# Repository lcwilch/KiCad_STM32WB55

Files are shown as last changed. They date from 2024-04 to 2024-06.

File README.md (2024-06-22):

# KiCad_STM32WB55
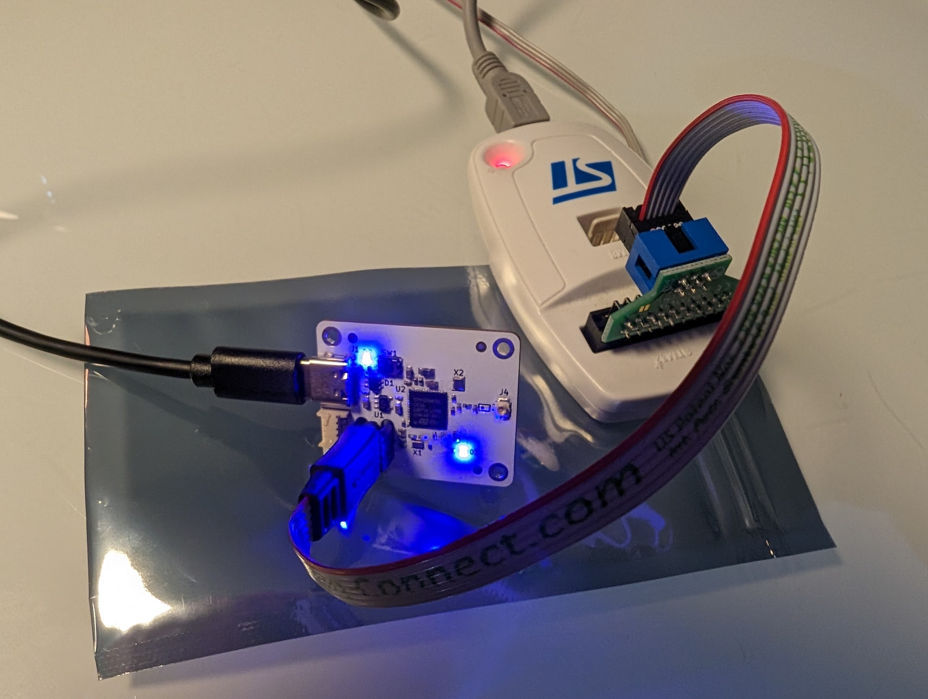
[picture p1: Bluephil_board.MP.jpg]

Finished https://www.youtube.com/watch?v=nkHFoxe0mrU&amp;t=3668s and successfully manufactured and brought-up board pictured above

# Bluephil
Contains KiCad project and manufacturing files and information
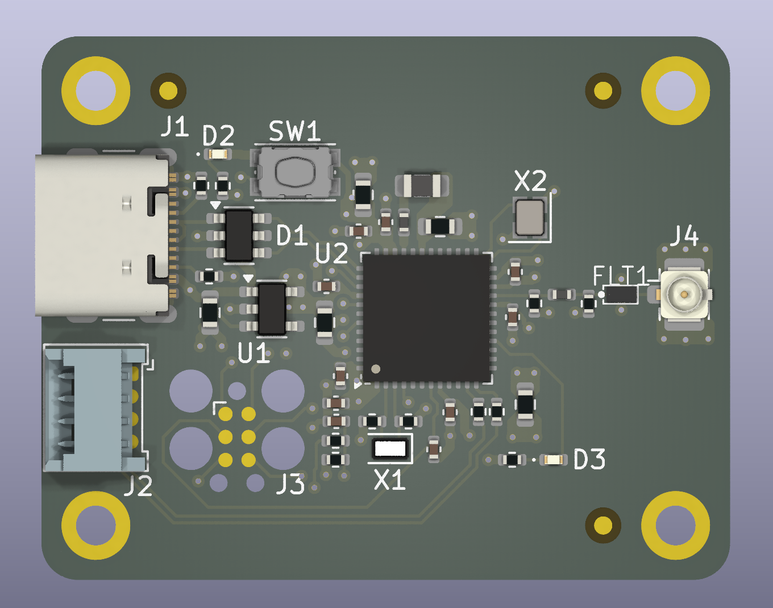
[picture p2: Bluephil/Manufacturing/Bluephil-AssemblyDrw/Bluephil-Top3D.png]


# STM32CubeIDE
Contains a STM32CubeIDE project that tests board SWD interface (for flashing and debug), debug LED GPIO, and USB FS CDC functionality

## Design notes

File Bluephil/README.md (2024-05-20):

# KiCad
Most files in this dir are related to the KiCad project

# Manufacturing
Contains files needed to manufacture board: Gerbers, BOM, component placement
Also contains assembly drawings and engineering/technical questions and answers when manufacturing via PCBWay

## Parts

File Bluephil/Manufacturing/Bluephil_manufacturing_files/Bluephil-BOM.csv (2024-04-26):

Reference | Value | Footprint | Qty | DNP | Description | Manufacturer | Manufacturer PN | Distributor Link
C1,C2,C3,C8,C16 | 4u7 | Resistor_SMD:R_0603_1608Metric | 5 |  | Unpolarized capacitor | Murata Electronics | GRM188Z71A475KE15J | https://www.mouser.com/ProductDetail/Murata-Electronics/GRM188Z71A475KE15J?qs=Ey7%2FXF42M3fe52ZB0l7gLw%3D%3D
C4,C5,C6,C7,C9,C10,C11,C12,C15,C19 | 100n | Capacitor_SMD:C_0402_1005Metric | 10 |  | Unpolarized capacitor | Murata Electronics | GRM155R71A104KA01J | https://www.mouser.com/ProductDetail/Murata-Electronics/GRM155R71A104KA01J?qs=9U7yHM2lsjQpBoriOS9Iag%3D%3D
C13,C14 | 10p | Resistor_SMD:R_0402_1005Metric | 2 |  | Unpolarized capacitor | KYOCERA AVX | 04026D100JAT2A | https://www.mouser.com/ProductDetail/KYOCERA-AVX/04026D100JAT2A?qs=gEbkM7q0lx%252BmQLS7sqmBjQ%3D%3D
C17 | 0p8 | Resistor_SMD:R_0402_1005Metric | 1 |  | Unpolarized capacitor | Murata Electronics | GRM1555C1HR80BA01D | https://www.mouser.com/ProductDetail/Murata-Electronics/GRM1555C1HR80BA01D?qs=e%252BE4OD6MgMezPYPintwvrA%3D%3D
C18 | 0p3 | Resistor_SMD:R_0402_1005Metric | 1 |  | Unpolarized capacitor | Murata Electronics | GRM1555C1HR30WA01D | https://www.mouser.com/ProductDetail/Murata-Electronics/GRM1555C1HR30WA01D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
D1 | USBLC6-2SC6 | Package_TO_SOT_SMD:SOT-23-6 | 1 |  | Very low capacitance ESD protection diode, 2 data-line, SOT-23-6 | STMicroelectronics | USBLC6-2SC6 | https://www.mouser.com/ProductDetail/STMicroelectronics/USBLC6-2SC6?qs=po45yt2pPpu%2FhNIlwQdTlg%3D%3D
D2,D3 | LED | LED_SMD:LED_0402_1005Metric | 2 |  | Light emitting diode | Kingbright | APHHS1005LQBC/D-V | https://www.mouser.com/ProductDetail/Kingbright/APHHS1005LQBC-D-V?qs=WbpYJYa8y32aFVn6IIj1Dg%3D%3D
FLT1 | DLF162500LT-5028A1 | Bluephil_PCBFootprints:DLF162500LT-5028A1 | 1 |  | Signal Conditioning LTCC LOW PASS FLTR 2400-2500MHz | TDK | DLF162500LT-5028A1 | https://www.mouser.com/ProductDetail/TDK/DLF162500LT-5028A1?qs=U%2FZX79kHR%2FlwIbAISCs3qA%3D%3D
J1 | USB_C_Receptacle_USB2.0_16P | Connector_USB:USB_C_Receptacle_GCT_USB4105-xx-A_16P_TopMnt_Horizontal | 1 |  | USB 2.0-only 16P Type-C Receptacle connector | GCT | USB4105-GF-A | https://www.mouser.com/ProductDetail/GCT/USB4105-GF-A?qs=KUoIvG%2F9IlY%2FMLlBMpStpA%3D%3D
J3 | Conn_01x04 | Connector_Molex:Molex_PicoBlade_53048-0410_1x04_P1.25mm_Horizontal | 1 |  | Generic connector, single row, 01x04, script generated (kicad-library-utils/schlib/autogen/connector/) | Molex | 53048-0410 | https://www.mouser.com/ProductDetail/Molex/53048-0410?qs=359VwiUTsp2msj5Tobchuw%3D%3D
J4 | Conn_Coaxial | Connector_Coaxial:U.FL_Hirose_U.FL-R-SMT-1_Vertical | 1 |  | coaxial connector (BNC, SMA, SMB, SMC, Cinch/RCA, LEMO, ...) | Hirose Connector | U.FL-R-SMT-1(10) | https://www.mouser.com/ProductDetail/Hirose-Connector/U.FL-R-SMT-110?qs=kL1ClTr6oBoOdtqlGQpQrQ%3D%3D
L1 | 10n | Inductor_SMD:L_0402_1005Metric | 1 |  | Inductor | Murata Electronics | LQG15WZ10NJ02D | https://www.mouser.com/ProductDetail/Murata-Electronics/LQG15WZ10NJ02D?qs=60uY6ySkanT1eJ7IaeAl%2Fg%3D%3D
L2 | 10u | Inductor_SMD:L_0805_2012Metric | 1 |  | Inductor | Murata Electronics | LQM21FN100M70L | https://www.mouser.com/ProductDetail/Murata-Electronics/LQM21FN100M70L?qs=8M15sSGRUn%252BogwBrvQUwLA%3D%3D
L3 | 2n7 | Inductor_SMD:L_0402_1005Metric | 1 |  | Inductor | Murata Electronics | LQG15HS2N7S02D | https://www.mouser.com/ProductDetail/Murata-Electronics/LQG15HS2N7S02D?qs=ctz47l0uL1AKrLI74yO5Qw%3D%3D
R1,R2,R7 | 5k1 | Resistor_SMD:R_0402_1005Metric | 3 |  | Resistor | KOA Speer | SG73P1EWTTP512J | https://www.mouser.com/ProductDetail/KOA-Speer/SG73P1EWTTP512J?qs=Jslch3jnSjlSuuKTSTqkRg%3D%3D
R3,R4,R5,R6,R8 | 220R | Resistor_SMD:R_0402_1005Metric | 5 |  | Resistor | KOA Speer | RK73H1ETTP2200F | https://www.mouser.com/ProductDetail/KOA-Speer/RK73H1ETTP2200F?qs=RHoMK1iCi09D%2FnGG1bjdHg%3D%3D
SW1 | SW_Push | Button_Switch_SMD:SW_Push_1P1T_NO_CK_KMR2 | 1 |  | Push button switch, generic, two pins | C&K | KMR231NGLFS | https://www.mouser.com/ProductDetail/CK/KMR231NGLFS?qs=sb%252But3Lm4x1Y5NsXXdZx2g%3D%3D
U1 | MIC5365-3.3YD5 | Package_TO_SOT_SMD:SOT-23-5 | 1 |  | 150mA Low-dropout Voltage Regulator, Vout 3.3V, Vin up to 5.5V, SOT-23-5 | Microchip Technology | MIC5365-3.3YD5-TR | https://www.mouser.com/ProductDetail/Microchip-Technology/MIC5365-3.3YD5-TR?qs=U6T8BxXiZAXzRinbbfZRrg%3D%3D
U2 | STM32WB55CEU6 | Package_DFN_QFN:QFN-48-1EP_7x7mm_P0.5mm_EP5.6x5.6mm | 1 |  | STMicroelectronics Arm Cortex-M4 MCU, 512KB flash, 256KB RAM, 64 MHz, 1.71-3.6V, 30 GPIO, UFQFPN48 | STMicroelectronics | STM32WB55CEU6 | https://www.mouser.com/ProductDetail/STMicroelectronics/STM32WB55CEU6?qs=l7cgNqFNU1h38DnIgipayw%3D%3D
X1 | 32k768 | Crystal:Crystal_SMD_2012-2Pin_2.0x1.2mm | 1 |  | Two pin crystal | NDK | NX2012SA-32.768K-STD-MUB-1 | https://www.mouser.com/ProductDetail/NDK/NX2012SA-32.768K-STD-MUB-1?qs=55YtniHzbhA%252B6%2Fl1MwFZaQ%3D%3D
X2 | 32M | Crystal:Crystal_SMD_2016-4Pin_2.0x1.6mm | 1 |  | Four pin crystal, GND on pins 2 and 4 | NDK | NX2016SA-32M-EXS00A-CS06465 | https://www.mouser.com/ProductDetail/NDK/NX2016SA-32M-EXS00A-CS06465?qs=w%2Fv1CP2dgqr82b0JjRnv4A%3D%3D

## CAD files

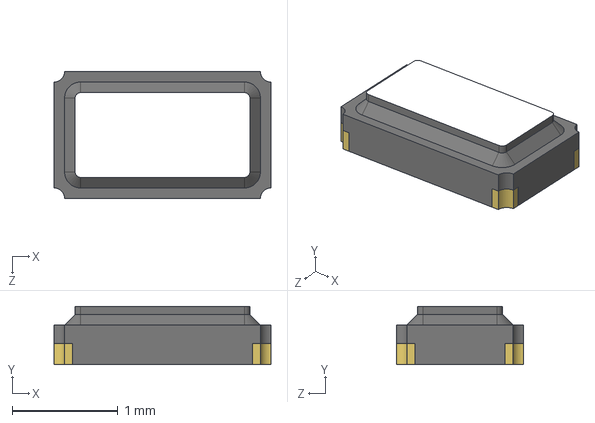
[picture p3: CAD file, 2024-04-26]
Bluephil/3DModels/NX2012SA-32.768K-STD-MUB-1.stp
2.05 x 0.55 x 1.20 mm

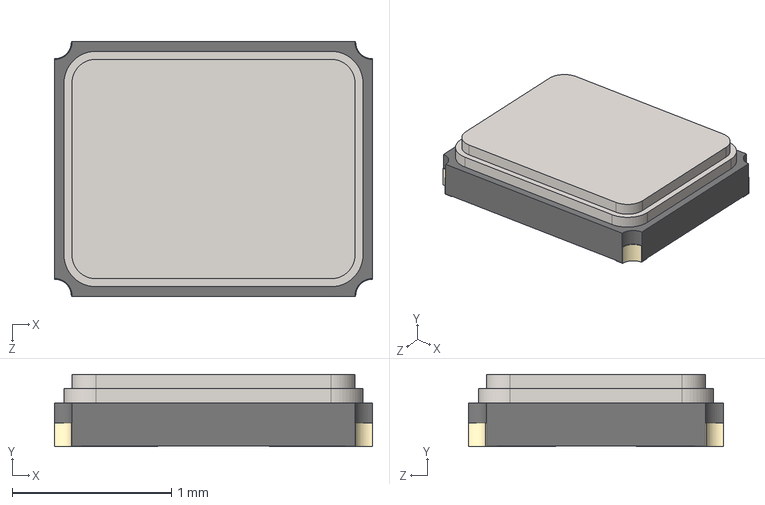
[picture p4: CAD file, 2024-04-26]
Bluephil/3DModels/NX2016SA-32M-EXS00A-CS06465.stp
2.00 x 0.455 x 1.60 mm

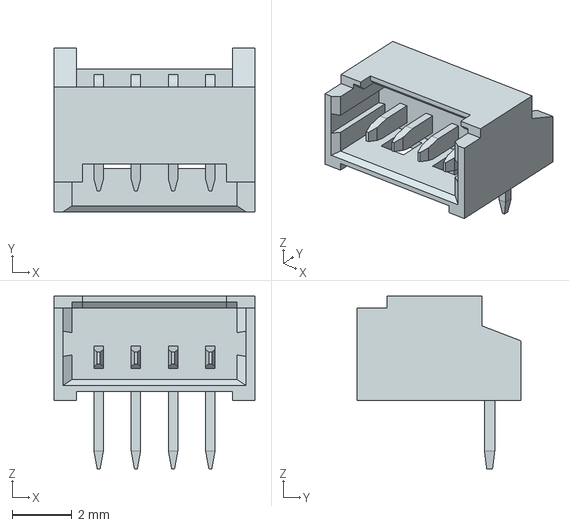
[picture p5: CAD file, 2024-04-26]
Bluephil/3DModels/Molex_PicoBlade_53048-0410_1x04_P1.25mm_Horizontal.stp
6.75 x 5.50 x 5.80 mm

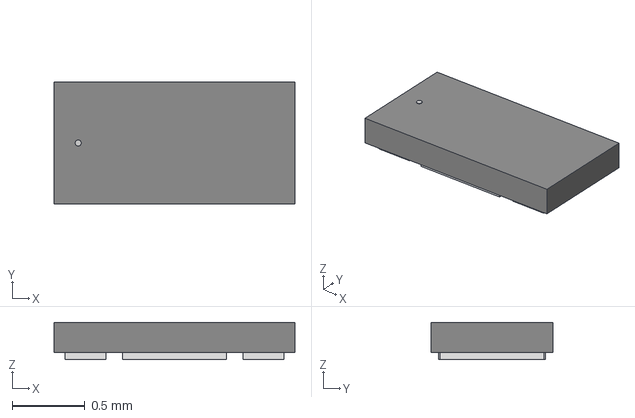
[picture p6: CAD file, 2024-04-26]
Bluephil/3DModels/DLF-4_1P6X0P8.step
1.65 x 0.838 x 0.257 mm

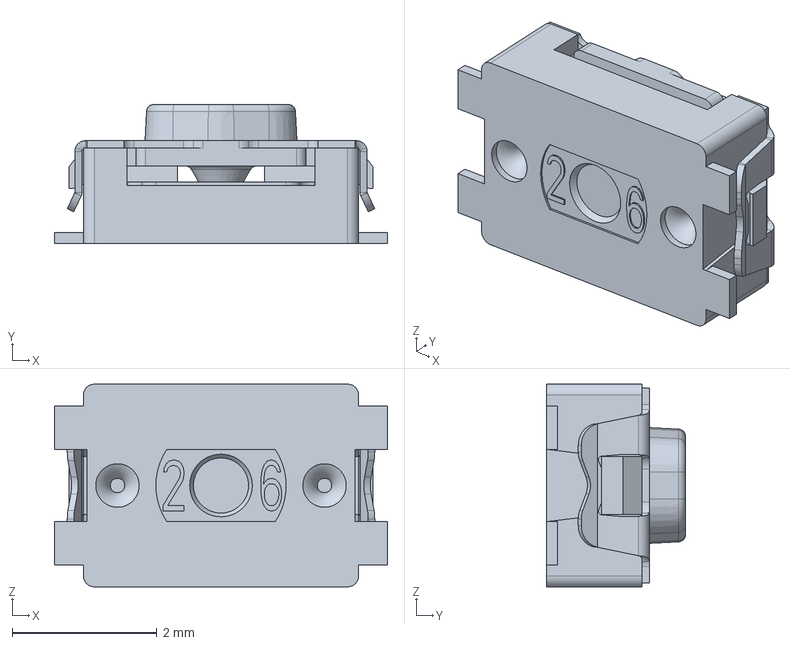
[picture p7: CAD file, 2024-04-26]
Bluephil/3DModels/KMR231NGLFS.stp
4.60 x 1.92 x 2.80 mm

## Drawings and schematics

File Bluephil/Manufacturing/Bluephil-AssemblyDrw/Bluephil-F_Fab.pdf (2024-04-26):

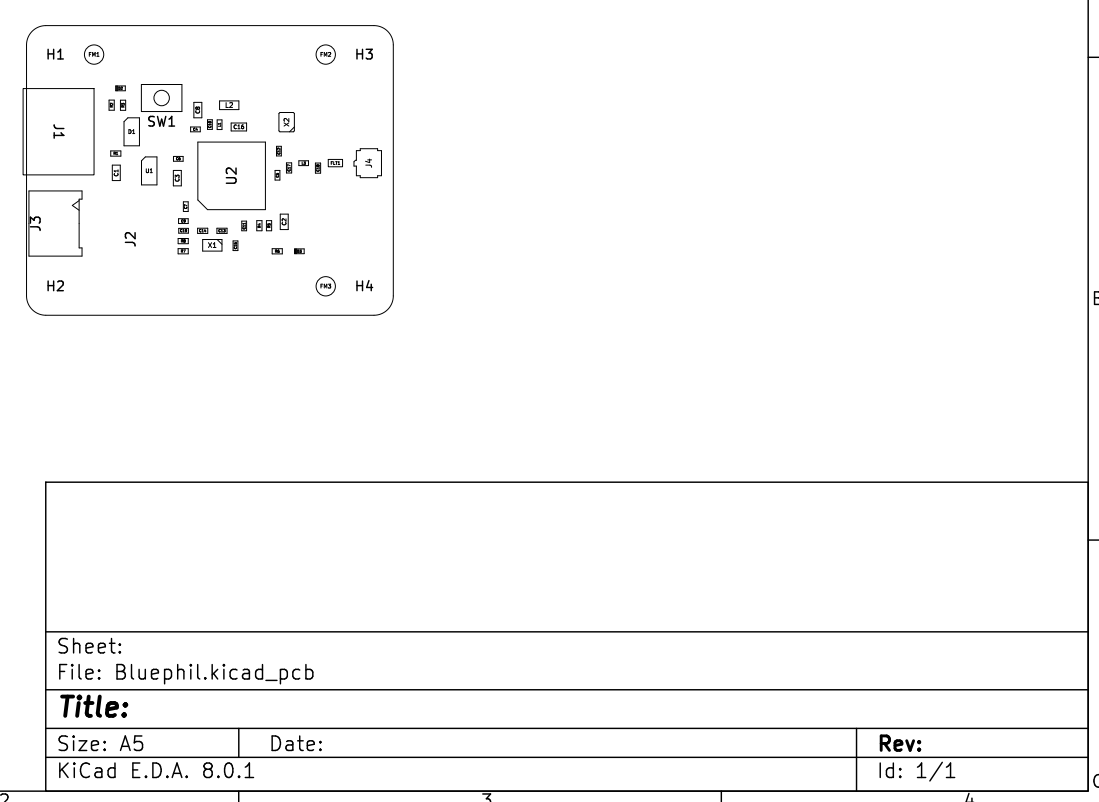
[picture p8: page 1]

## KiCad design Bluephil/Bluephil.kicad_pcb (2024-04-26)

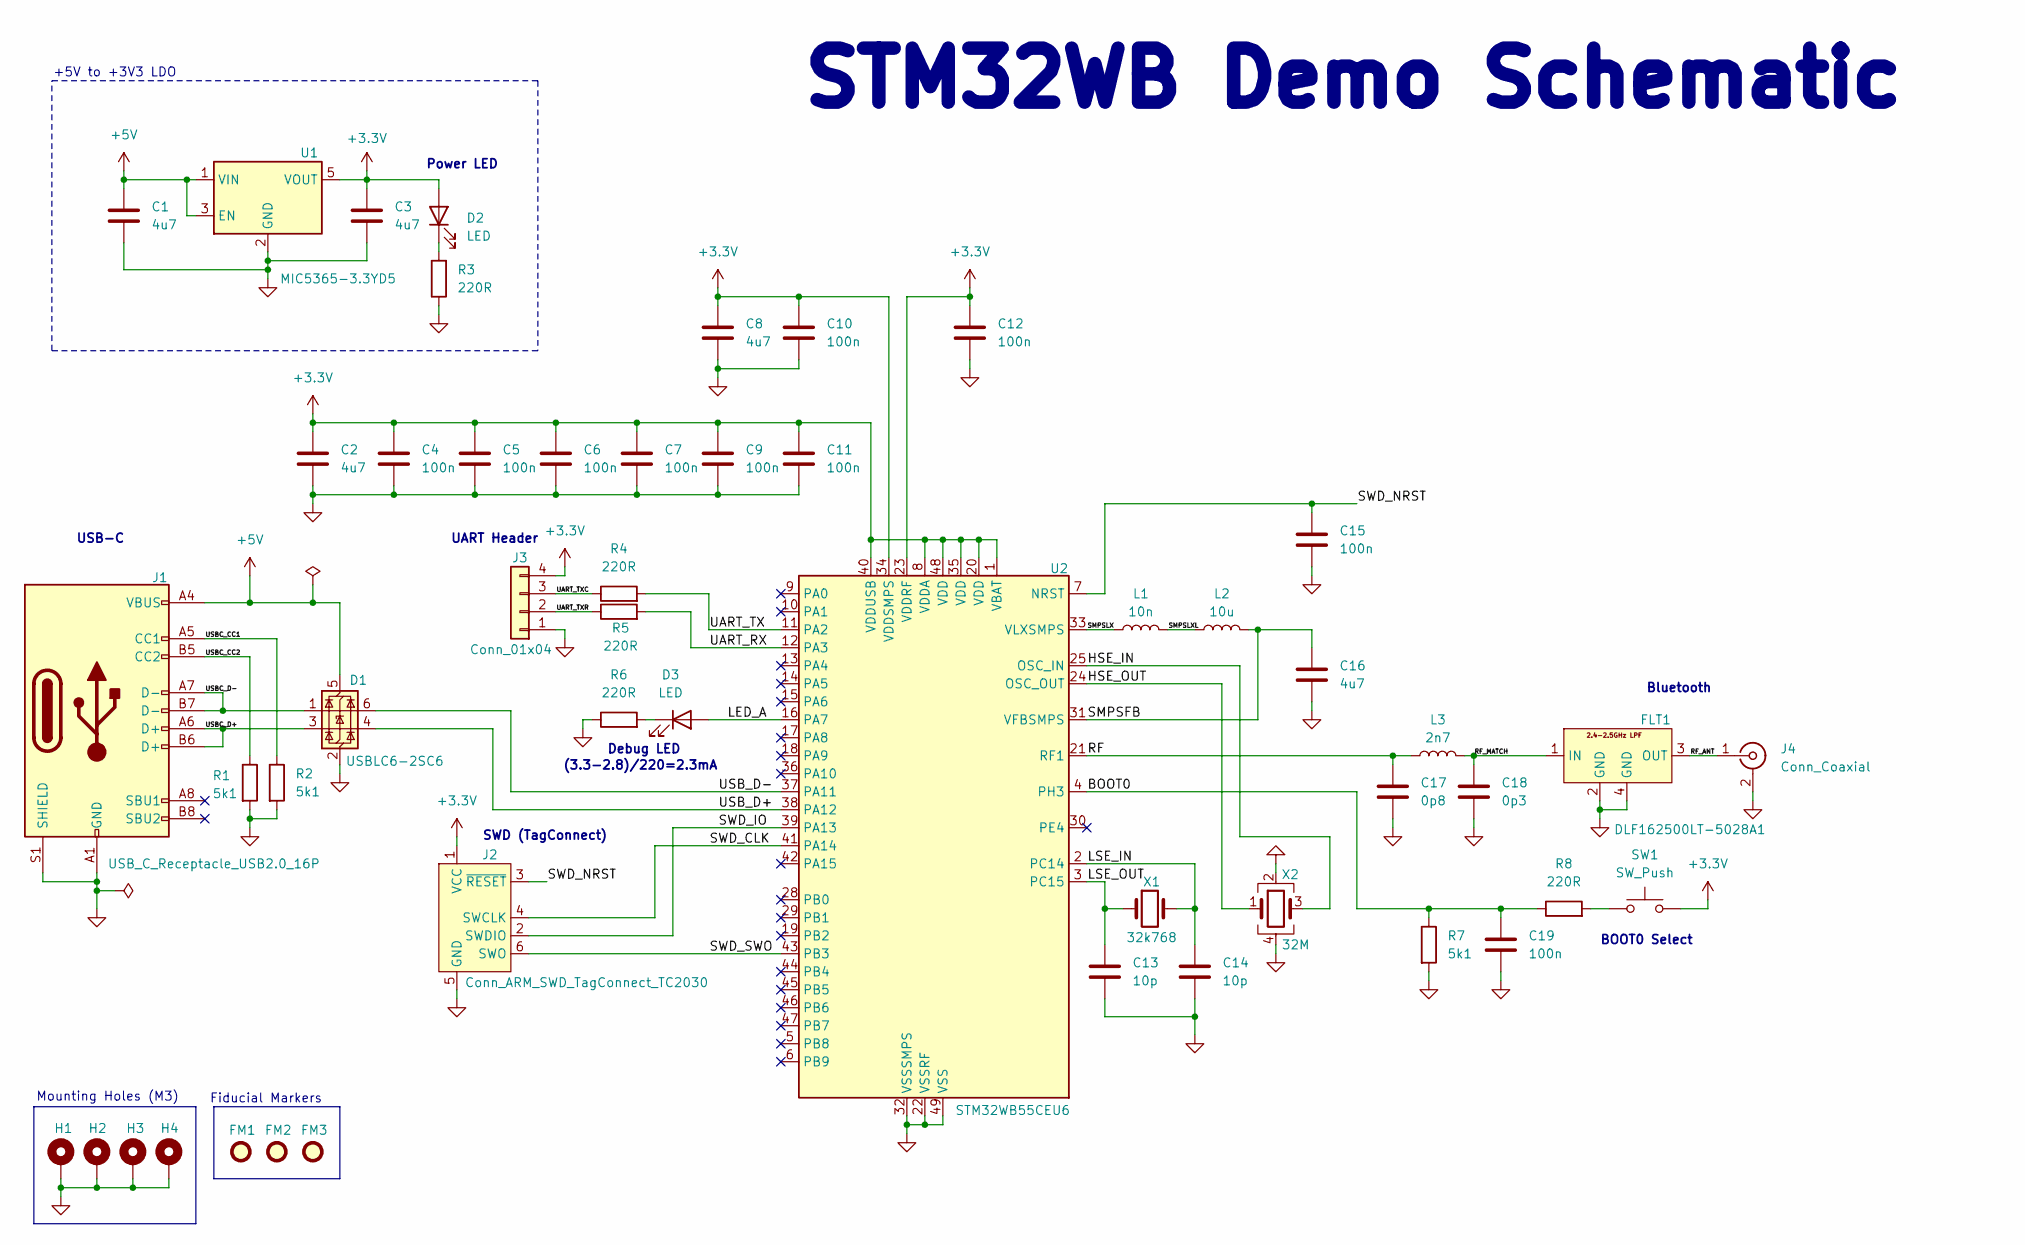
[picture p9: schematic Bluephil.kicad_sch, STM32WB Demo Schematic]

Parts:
C1, C2, C3, C8, C16: 4u7; R_0603_1608Metric; Manufacturer PN GRM188Z71A475KE15J
C4, C5, C6, C7, C9, C10, C11, C12, C15, C19: 100n; C_0402_1005Metric; Manufacturer PN GRM155R71A104KA01J
C13, C14: 10p; R_0402_1005Metric; Manufacturer PN 04026D100JAT2A
C17: 0p8; R_0402_1005Metric; Manufacturer PN GRM1555C1HR80BA01D
C18: 0p3; R_0402_1005Metric; Manufacturer PN GRM1555C1HR30WA01D
D1: USBLC6-2SC6; SOT-23-6; Manufacturer PN USBLC6-2SC6
D2, D3: LED; LED_0402_1005Metric; Manufacturer PN APHHS1005LQBC/D-V
FLT1: DLF162500LT-5028A1; Manufacturer PN DLF162500LT-5028A1
FM1, FM2, FM3: Fiducial; Fiducial_1mm_Mask2mm
H1, H2, H3, H4: MountingHole_Pad; MountingHole_2.2mm_M2_DIN965_Pad
J1: USB_C_Receptacle_USB2.0_16P; USB_C_Receptacle_GCT_USB4105-xx-A_16P_TopMnt_Horizontal; Manufacturer PN USB4105-GF-A
J2: Conn_ARM_SWD_TagConnect_TC2030; Tag-Connect_TC2030-IDC-FP_2x03_P1.27mm_Vertical
J3: Conn_01x04; Molex_PicoBlade_53048-0410_1x04_P1.25mm_Horizontal; Manufacturer PN 53048-0410
J4: Conn_Coaxial; U.FL_Hirose_U.FL-R-SMT-1_Vertical; Manufacturer PN U.FL-R-SMT-1(10)
L1: 10n; L_0402_1005Metric; Manufacturer PN LQG15WZ10NJ02D
L2: 10u; L_0805_2012Metric; Manufacturer PN LQM21FN100M70L
L3: 2n7; L_0402_1005Metric; Manufacturer PN LQG15HS2N7S02D
R1, R2, R7: 5k1; R_0402_1005Metric; Manufacturer PN SG73P1EWTTP512J
R3, R4, R5, R6, R8: 220R; R_0402_1005Metric; Manufacturer PN RK73H1ETTP2200F
SW1: SW_Push; SW_Push_1P1T_NO_CK_KMR2; Manufacturer PN KMR231NGLFS
U1: MIC5365-3.3YD5; SOT-23-5; Manufacturer PN MIC5365-3.3YD5-TR
U2: STM32WB55CEU6; QFN-48-1EP_7x7mm_P0.5mm_EP5.6x5.6mm; Manufacturer PN STM32WB55CEU6
X1: 32k768; Crystal_SMD_2012-2Pin_2.0x1.2mm; Manufacturer PN NX2012SA-32.768K-STD-MUB-1
X2: 32M; Crystal_SMD_2016-4Pin_2.0x1.6mm; Manufacturer PN NX2016SA-32M-EXS00A-CS06465

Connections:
+3.3V: C2.1, C3.1, C4.1, C5.1, C6.1, C7.1, C8.1, C9.1, C10.1, C11.1, C12.1, D2.2 (A), J2.1 (VCC), J3.4, SW1.2, U1.5 (VOUT), U2.1 (VBAT), U2.8 (VDDA), U2.20 (VDD), U2.23 (VDDRF), U2.34 (VDDSMPS), U2.35 (VDD), U2.40 (VDDUSB), U2.48 (VDD)
+5V: C1.1, D1.5 (VBUS), J1.A4 (VBUS), J1.A9 (VBUS), J1.B4 (VBUS), J1.B9 (VBUS), U1.1 (VIN), U1.3 (EN)
/BOOT0: C19.1, R7.1, R8.1, U2.4 (PH3)
/HSE_IN: U2.25 (OSC_IN), X2.3
/HSE_OUT: U2.24 (OSC_OUT), X2.1
/LED_A: D3.2 (A), U2.16 (PA7)
/LSE_IN: C14.1, U2.2 (PC14), X1.2
/LSE_OUT: C13.1, U2.3 (PC15), X1.1
/RF: C17.1, L3.1, U2.21 (RF1)
/RF_ANT: FLT1.3 (OUT), J4.1 (In)
/RF_MATCH: C18.1, FLT1.1 (IN), L3.2
/SMPSFB: C16.1, L2.2, U2.31 (VFBSMPS)
/SMPSLX: L1.1, U2.33 (VLXSMPS)
/SMPSLXL: L1.2, L2.1
/SWD_CLK: J2.4 (SWCLK), U2.41 (PA14)
/SWD_IO: J2.2 (SWDIO), U2.39 (PA13)
/SWD_NRST: C15.1, J2.3 (~RESET), U2.7 (NRST)
/SWD_SWO: J2.6 (SWO), U2.43 (PB3)
/UART_RX: R5.2, U2.12 (PA3)
/UART_TX: R4.2, U2.11 (PA2)
/UART_TXC: J3.3, R4.1
/UART_TXR: J3.2, R5.1
/USBC_CC1: J1.A5 (CC1), R2.1
/USBC_CC2: J1.B5 (CC2), R1.1
/USBC_D+: D1.3 (I/O2), J1.A6 (D+), J1.B6 (D+)
/USBC_D-: D1.1 (I/O1), J1.A7 (D-), J1.B7 (D-)
/USB_D+: D1.4 (I/O2), U2.38 (PA12)
/USB_D-: D1.6 (I/O1), U2.37 (PA11)
GND: C1.2, C2.2, C3.2, C4.2, C5.2, C6.2, C7.2, C8.2, C9.2, C10.2, C11.2, C12.2, C13.2, C14.2, C15.2, C16.2, C17.2, C18.2, C19.2, D1.2 (GND), FLT1.2 (GND), FLT1.4 (GND), H1.1, H2.1, H3.1, H4.1, J1.A1 (GND), J1.A12 (GND), J1.B1 (GND), J1.B12 (GND), J1.S1 (SHIELD), J2.5 (GND), J3.1, J4.2 (Ext), R1.2, R2.2, R3.1, R6.1, R7.2, U1.2 (GND), U2.22 (VSSRF), U2.32 (VSSSMPS), U2.49 (VSS), X2.2, X2.4
unnamed: D2.1 (K), R3.2
unnamed: D3.1 (K), R6.2
unnamed: R8.2, SW1.1

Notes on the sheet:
BOOT0 Select
UART Header
Bluetooth
+5V to +3V3 LDO
Power LED
Fiducial Markers
SWD (TagConnect)
Mounting Holes (M3)
STM32WB Demo Schematic
USB-C
Debug LED
(3.3-2.8)/220=2.3mA

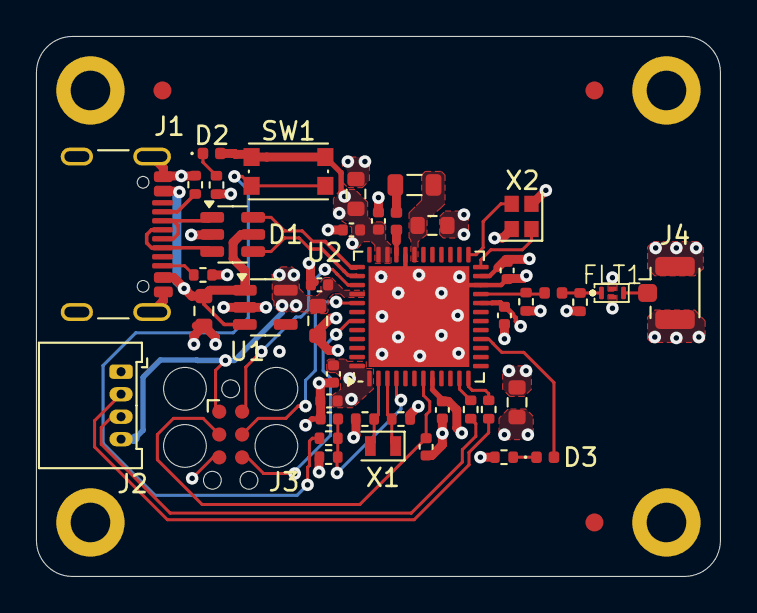
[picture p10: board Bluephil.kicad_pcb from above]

Board: 4 copper layers, 38.0 x 30.0 mm, 50 parts (0 on the bottom side), 32 nets.

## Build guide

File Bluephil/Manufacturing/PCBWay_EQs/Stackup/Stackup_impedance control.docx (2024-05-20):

Engineering stackup & impedance

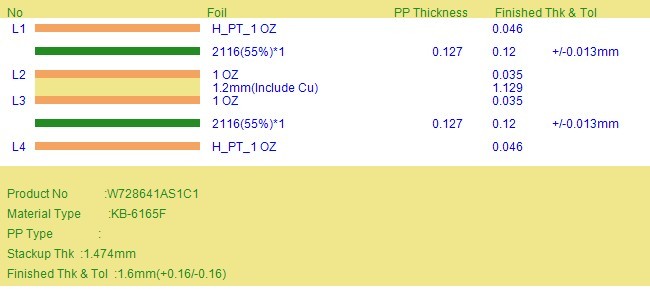
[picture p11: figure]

Product No ：W728641AS1C1 Stackup Information:

Impedance Information:

index | Imp style | CTL | REF | OrigTr | OrigS | origG | AdjTrace | AdjSpace | AdjGaurdi | Cust Imp | CALC imp
1 | Single-ended | L1 | L2 | 6.69 | | | 7.49 | | | 50 | 50+/-5Ω
2 | Single-ended | L4 | L3 | 6.69 | | | 7.49 | | | 50 | 50+/-5Ω
3 | Differential | L1 | L2 | 6.69 | 8.31 | | 7.29 | 7.71 | | 90 | 90+/-9Ω

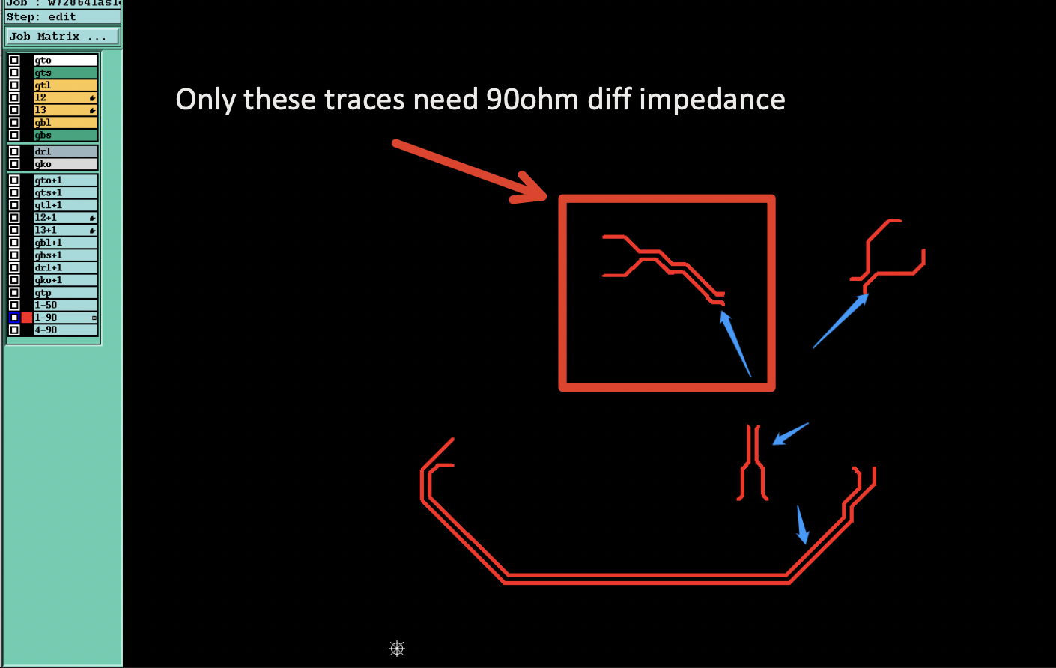
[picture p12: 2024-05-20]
Bluephil/Manufacturing/PCBWay_EQs/Impedance_Controlled_traces/bluephil_diff_pair_eq_answer.png

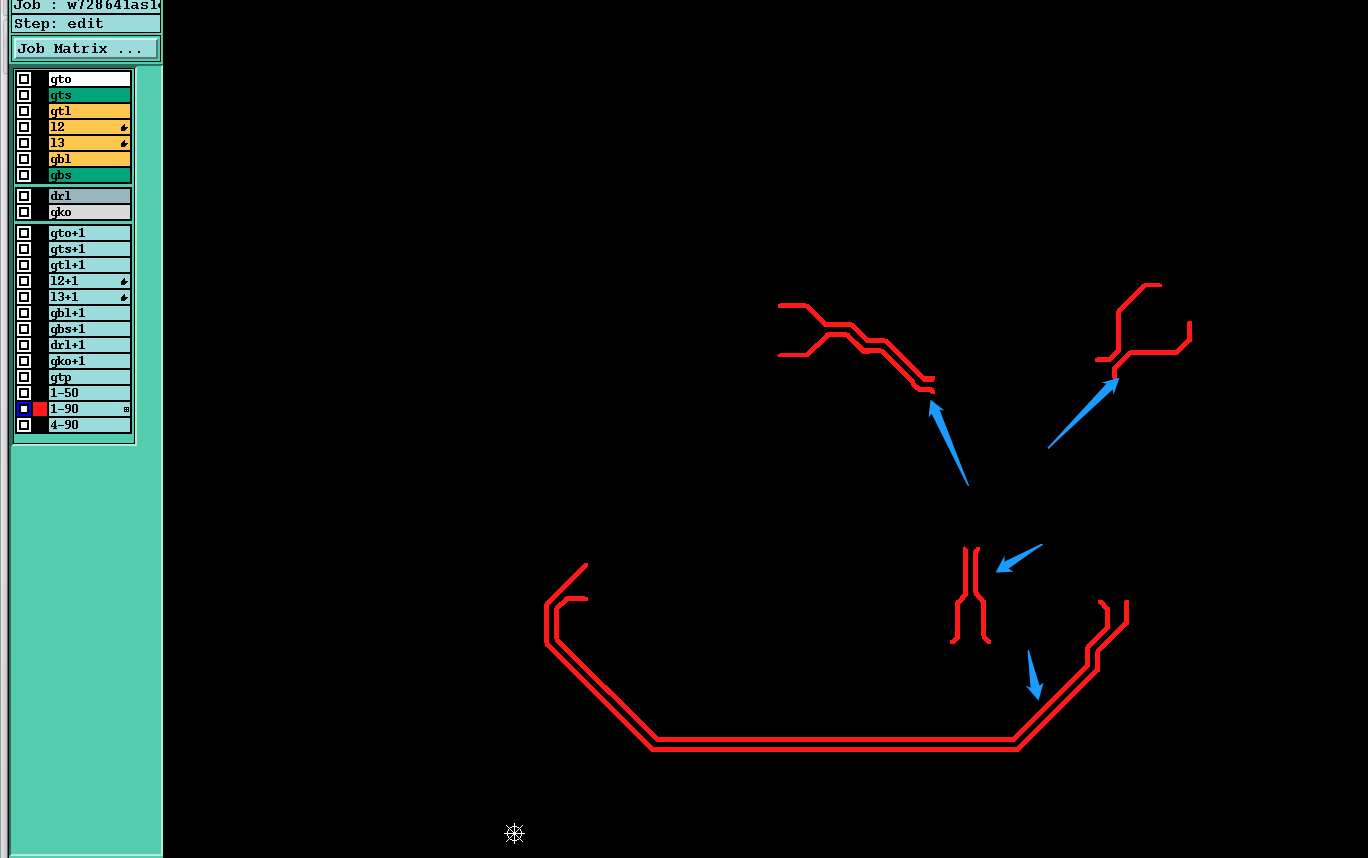
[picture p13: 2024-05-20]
Bluephil/Manufacturing/PCBWay_EQs/Impedance_Controlled_traces/bluephil_diff_pair_eq.png

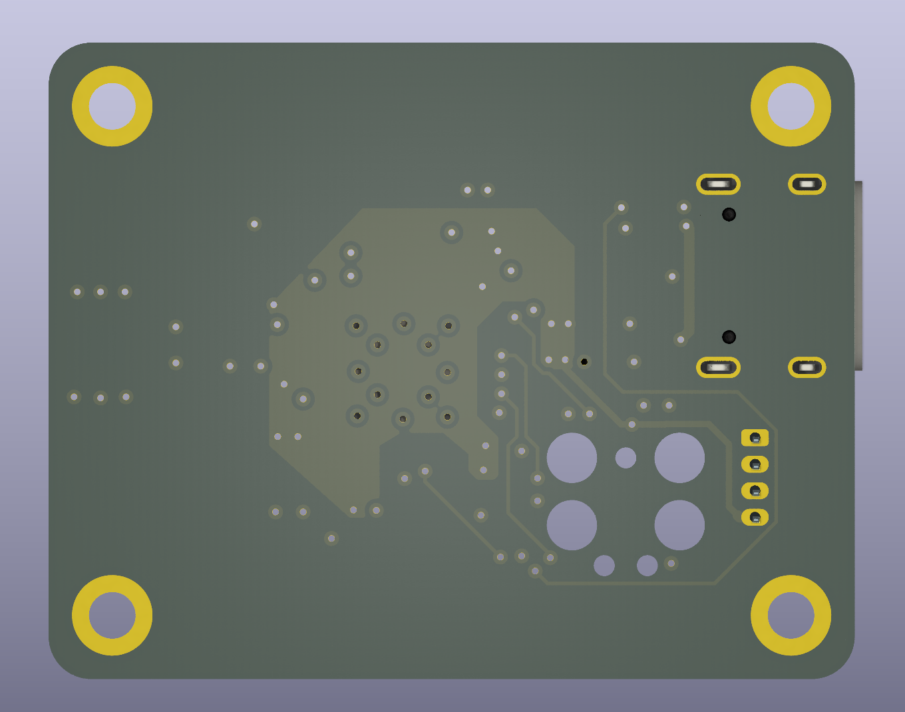
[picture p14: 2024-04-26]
Bluephil/Manufacturing/Bluephil-AssemblyDrw/Bluephil-Bot3D.png

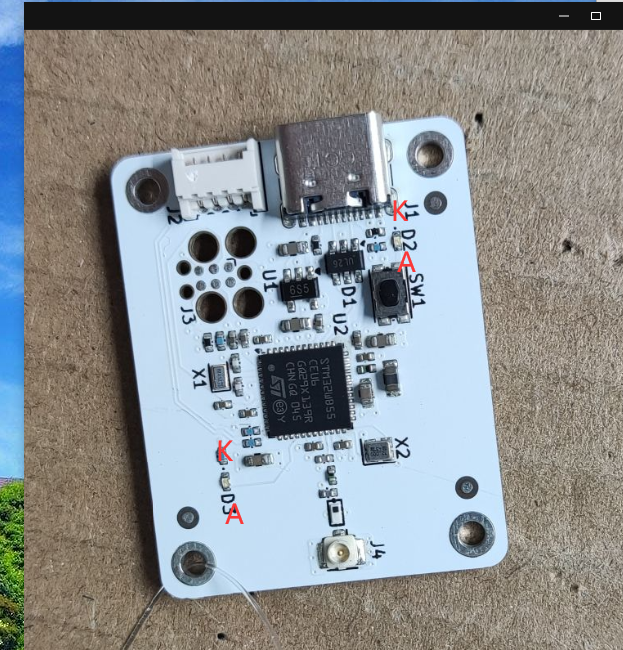
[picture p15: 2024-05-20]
Bluephil/Manufacturing/PCBWay_EQs/Assembly_Confirmation/pic3 for led, pls cfm the orientation.jpg

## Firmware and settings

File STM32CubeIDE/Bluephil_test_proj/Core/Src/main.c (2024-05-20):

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
/* Includes ------------------------------------------------------------------*/
#include "main.h"
#include "usb_device.h"


void SystemClock_Config(void);
void PeriphCommonClock_Config(void);
static void MX_GPIO_Init(void);
/**
  * @brief  The application entry point.
  * @retval int
  */
int main(void)
{

  /* MCU Configuration--------------------------------------------------------*/

  /* Reset of all peripherals, Initializes the Flash interface and the Systick. */
  HAL_Init();

  /* Configure the system clock */
  SystemClock_Config();

/* Configure the peripherals common clocks */
  PeriphCommonClock_Config();

  /* Initialize all configured peripherals */
  MX_GPIO_Init();
  MX_USB_Device_Init();
  /* Infinite loop */
  /* USER CODE BEGIN WHILE */
  uint32_t count = 0;
  uint8_t message[64] = {0};
  while (1)
  {
    HAL_Delay(900);
    sprintf((char*)message, "Hello, world %lu!\r\n", ++count);
    CDC_Transmit_FS(message, sizeof(message));
    HAL_GPIO_TogglePin(Debug_LED_GPIO_Port, Debug_LED_Pin);
    HAL_Delay(100);
    HAL_GPIO_TogglePin(Debug_LED_GPIO_Port, Debug_LED_Pin);
    /* USER CODE END WHILE */

    /* USER CODE BEGIN 3 */
  }
  /* USER CODE END 3 */
}

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


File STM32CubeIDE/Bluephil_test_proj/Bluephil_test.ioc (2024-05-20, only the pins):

Mcu.UserName=STM32WB55CEUx
PA11.Signal=USB_DM
PA12.Signal=USB_DP
PA7.GPIO_Label=Debug_LED
PA7.Signal=GPIO_Output
PC14-OSC32_IN.Signal=RCC_OSC32_IN
PC15-OSC32_OUT.Signal=RCC_OSC32_OUT

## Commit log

2024-04-26 Just submitted board for quote from PCBWay.
    [Bluephil-BOM.csv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]
2024-05-20 Added STM32CubeIDE project that tests board debug LED and USB FS CDC functionality.
2024-05-20 Organizing repo to finsih project.
    [Bluephil-BOM.csv]

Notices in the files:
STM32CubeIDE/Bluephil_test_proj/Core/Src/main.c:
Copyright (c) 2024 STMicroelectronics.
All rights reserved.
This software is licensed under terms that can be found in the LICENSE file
